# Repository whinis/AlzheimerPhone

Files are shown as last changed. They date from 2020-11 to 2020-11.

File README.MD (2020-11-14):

# Arduino Alzheimers Phone

A project for a friend. This modifies a Cordtelco 2500 model telephone so that it 
effectively only works as a speed dial however has a 911 override. Its designed with 
alzheimers in mind so that if the person continues to try and dial the phone only 
the first number matters fixing what is seen as a defect in current phones you can buy for alzheimers.

I have included the PCB in kicad I used to make this phone, Also the arduino code. The board uses a
at328p microprocessor with an 8mhz crystal as the voltage on a phone line can vary wildly and 5v cannot
be assured. It programs as if its an arduino pro mini

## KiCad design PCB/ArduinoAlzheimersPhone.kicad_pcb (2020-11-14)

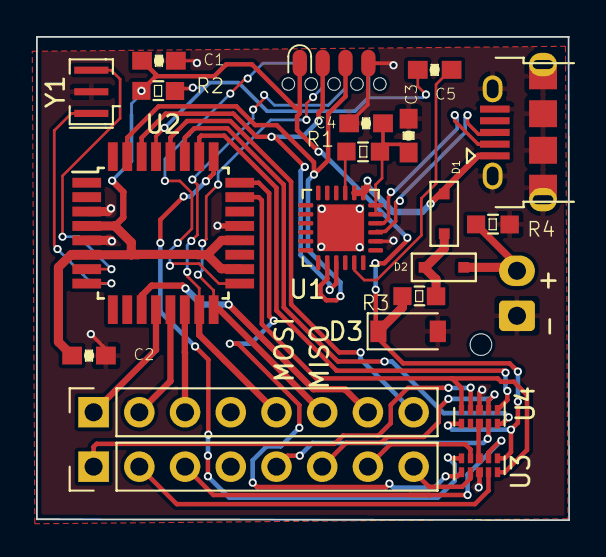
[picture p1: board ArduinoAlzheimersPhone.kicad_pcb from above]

Board: 2 copper layers, 29.6 x 26.8 mm, 22 parts (0 on the bottom side), 36 nets.

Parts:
C1, C3: 1uf; C0603
C2, C4, C5: 100nf; C0603
D1, D2: 1N4148WX-TP; SOD-323
D3: 5.1V; D_SOD-123
J1: Conn_02x04_Odd_Even; SOIC_clipProgSmall
J2: USB_B_Micro; USB_Micro-B_Amphenol_10118194-0001LF_Horizontal
J3: Conn_01x08; PinHeader_1x08_P2.54mm_Vertical
J4: Conn_01x08; PinSocket_1x08_P2.54mm_Vertical
J5: Conn_01x02; JST_XH_B2B-XH-AM_1x02_P2.50mm_Vertical
R1, R2, R4: 10k; R0603
R3: 20; R0603
U1: CP2102N-A01-GQFN24; QFN-24-1EP_4x4mm_P0.5mm_EP2.6x2.6mm
U2: ATMEGA328P-MU; TQFP-32_7x7mm_P0.8mm
U3, U4: TMUX1204; USON-10_2.5x1.0mm_P0.5mm
Y1: 16mhz; Resonator_SMD_muRata_CSTxExxV-3Pin_3.0x1.1mm

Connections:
/3v3: C3.1, C4.1, R1.1, U1.5, U1.6
/5v: C1.1, C2.1, D3.1, J1.1, R2.1, R3.1, U2.4, U2.6, U2.18, U2.20, U3.6, U4.6
/5v_RAW: D1.C, D2.C, R3.2
/5v_USB: D1.A, J2.1, U1.7, U1.8
/10v: D2.A, J5.2, R4.1
/D+: J2.3, U1.3
/D-: J2.2, U1.4
/DTR: C5.2, U1.23
/KEYPAD_C1: J1.4, J4.6, U2.16
/KEYPAD_C2: J1.6, J4.5, U2.15
/KEYPAD_C3: J4.1, U2.12
/KEYPAD_COM: U3.8, U4.8
/KEYPAD_EN: U2.23, U3.5, U4.5
/KEYPAD_R1: J4.8, U2.28
/KEYPAD_R2: J4.7, U2.11
/KEYPAD_R3: J4.2, U2.13
/KEYPAD_R4: J4.3, U2.14
/PHONE_C1: J3.6, U4.2
/PHONE_C2: J3.5, U4.9
/PHONE_C3: J3.1, U4.4
/PHONE_C_A0: U2.26, U4.1
/PHONE_C_A1: U2.27, U4.10
/PHONE_R1: J3.8, U3.2
/PHONE_R2: J3.7, U3.9
/PHONE_R3: J3.2, U3.4
/PHONE_R4: J3.3, U3.7
/PHONE_R_A0: U2.24, U3.1
/PHONE_R_A1: U2.25, U3.10
/RST: C5.1, J1.8, R2.2, U2.29
/RX: J1.3, U1.21, U2.30
/SCK: J1.2, U2.17
/TX: J1.5, U1.20, U2.31
/USART_RST: R1.2, U1.9
GND: C1.2, C2.2, C3.2, C4.2, D3.2, J1.7, J2.5, J2.6, J5.1, R4.2, U1.2, U1.25, U2.3, U2.5, U2.21, U3.3, U4.3, Y1.2
unnamed: U2.7, Y1.3
unnamed: U2.8, Y1.1

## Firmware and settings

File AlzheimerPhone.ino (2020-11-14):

#include <Keypad.h>



#define ROW_NUM  4        //four rows
#define COLUMN_NUM  3       //three columns
#define NUMBER_SIZE 15

//Number dialed whenever corresponding key pad pressed

//To change which numbers are called just input them here
String dialer_mapping[12] = {
  {""}, // 0 
  {""}, // 1
  {""}, // 2
  {""}, // 3
  {""}, // 4
  {""}, // 5
  {""}, // 6
  {""}, // 7
  {""}, // 8
  {""}, // 9
  {""}, // *
  {""}  // #
};


char keys[ROW_NUM][COLUMN_NUM] = {
  {'1','2','3'},
  {'4','5','6'},
  {'7','8','9'},
  {'*','0','#'}
};



//Each number is Row A0 Row A1 Column A0 Column A1
int dialer[12][4] = {
  {1,1,1,0}, // 0 
  {0,0,0,0}, // 1
  {0,0,1,0}, // 2
  {0,0,0,1}, // 3
  {1,0,0,0}, // 4
  {1,0,1,0}, // 5
  {1,0,0,1}, // 6
  {0,1,0,0}, // 7
  {0,1,1,0}, // 8
  {0,1,0,1}, // 9
  {1,1,0,0}, // *
  {1,1,0,1}  // #
};


#define DIALER_EN A0

byte pin_rows[ROW_NUM] = {19, 7, 9, 10}; //connect to the row pinouts of the keypad
byte pin_column[COLUMN_NUM] = {12, 11, 8}; //connect to the column pinouts of the keypad

byte mux_control_pins[4] = {A1, A2, A3, A4}; //connect to the row pinouts of the keypad

Keypad keypad = Keypad( makeKeymap(keys), pin_rows, pin_column, ROW_NUM, COLUMN_NUM );

void setup(){
  Serial.begin(9600);
  for(int j = 0;j<4;j++){ //setup the pins for the muxing chips
    pinMode(mux_control_pins[j],OUTPUT);
  }
  pinMode(DIALER_EN,OUTPUT);
  Serial.println("Setup Complete");
}
String extract_number(int position){ //extract the number from the dialing map
  return dialer_mapping[position];
}

String emergency="";
int timer = 0;
bool dialed = 0;
bool key_pressed = 0;

void dial(String number){
  for(int i=0;i<number.length();i++){
    int k = number.charAt(i)-48; //get the correct index
    if(k < 0) //skip if too high or low
      continue;
    if(k > 11)
      continue;
    Serial.println(k);
    for(int j = 0;j<4;j++){
      digitalWrite(mux_control_pins[j],dialer[k][j]); //setup mux to dial this number
    }
    digitalWrite(DIALER_EN,1); //dial
    delay(50);                //pause to simulate button press
    digitalWrite(DIALER_EN,0); //disable muxes
    delay(150);                //pause to allow time for next button press
  }
}

void loop(){
  char tempNumber[15];
  String number_to_dial ="";
  if(timer > 0){ //timer for emergency number, only used if 9 is the first key pressed
    timer --;
    if(timer ==0 and !emergency.equals("911")){ //if timer reaches 0 and we never reached 911 then just dial 9
      Serial.println("No Emergency Dialing 9");
      emergency="";
      number_to_dial = extract_number(9);
    }
      
  }
  char key = keypad.getKey();
  if (key){
    Serial.println(key);
    if(key == 42) //If * set to 48+10 so it ends up being 10 in the end
      key = 48+10;
    else if(key == 35) //If # set to 48+11 so it ends up being 11 in the end
      key = 48+11; 
    key = key-48; //remove the 48 from standard ascii table
    if(key == 9 && !key_pressed){ //if number is 9 we might be trying to call 911
      Serial.print("Possible Emergency ");
      Serial.println(key);
      timer = 50;
      emergency+="9";
    }else if(key == 1 && emergency.length() > 0){ //if there is any number in emergency and 1 key was pressed continue dialing
      Serial.print("Possible Emergency ");
      Serial.println(key);
      emergency+="1";
      if(emergency.length() < 3){
        timer = 50;
      }else{
        timer = 0;
        number_to_dial = emergency;
        Serial.println("EMERGENCY DIALING 911");
        emergency="";
      }
    }else{
      Serial.print("Straight Dial ");
      Serial.println(key);
      delay(10);
      Serial.println(extract_number(key));
      number_to_dial = extract_number(key);
    }
    key_pressed = 1;
  }
  if(number_to_dial.length() > 0 && !dialed){ //if there a number to dial then dial it
    Serial.println(number_to_dial);
    dial(number_to_dial);
    number_to_dial = "";
    dialed = 1;
  }
  delay(50);
}
